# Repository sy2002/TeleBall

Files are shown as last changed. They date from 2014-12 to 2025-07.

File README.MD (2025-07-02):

TeleBall - Retro Handheld Game Console
======================================

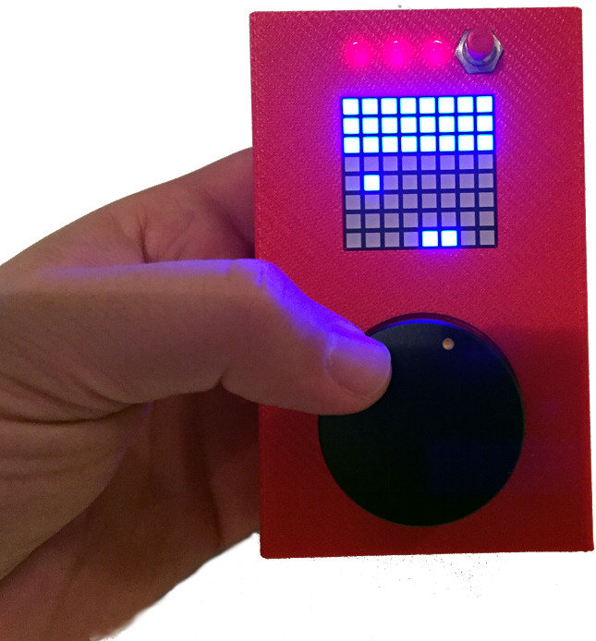
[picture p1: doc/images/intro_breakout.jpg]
DeviceInHand


What is TeleBall?
-----------------

TeleBall is a handheld game console. You cannot buy it. You need to build it
by yourself. It lets you play **BreakOut** in single-player mode using one
device and **Tennis for Two** in multi-player mode using two devices 
communicating via radio.

TeleBall is pretty retro and very minimalistic: It features an
8x8 pixel LED matrix display, a paddle as game controller and one button.
Therefore, the range of possible games is limited but you will be surprised
how much fun and even zenlike meditation this kind of gameplay can bring you,
particularly when you play Tennis for Two with a friend.

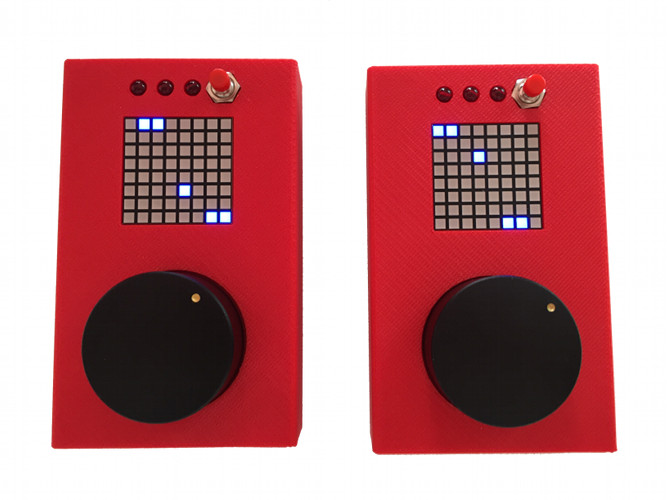
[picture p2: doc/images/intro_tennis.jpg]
TennisOnTwoDevices


About this GIT Repository
-------------------------

This repository contains everything you need to build your own TeleBall
device:

* CAD .stl and .cmb.gz data for your 3D printer or for any online 3D print
  shop to 3D print the TeleBall case

* Eagle PCB layout for any online PCB manufacturer to make the TeleBall PCB

* Part lists and hints how to build the hardware

* Arduino source code to flash the firmware

TeleBall is made using the
[Arduino Nano platform](https://store.arduino.cc/arduino-nano) on a
custom PCB.

Browse TeleBall's [project page](http://sy2002.github.io/TeleBall)
for a much better documentation, including a how-to play and
how-to build guide and a bill of materials (BOM). The project page
is also available offline using `index.html` in the root folder of
this repository.

### Folder Structure

    cad:    CAD data for 3D printing the TeleBall case
            Use ".stl" to modify the design or to create a custom output file.
            Most online 3D print shops can use the ".cmb.gz" for production.
            Made with FreeCad: https://FreeCAD.Org

    doc:    HTML documentation; use `index.html` in root folder to browse

    eagle:  Electronic schematic diagram including PCB layout.
            The libraries.zip files are only needed, if you want to modify
            anything; otherwise you can just send the ".brd" file to any
            online PCB manufacturing company to receive a TeleBall PCB.
            Made with the freeware version of Eagle: http://www.cadsoftusa.com

    src:    Arduino source code aka Sketch in the subfolder "TeleBall".
            Compile and upload it to your device using Arduino's IDE. You need
            to install the libraries from libraries.zip first, before being
            able to compile. The "archive" folder contains historic versions.
            Made with Arduino: http://arduino.cc/de/Main/Software

The Makers
----------

TeleBall is brought to you by

* [sy2002](http://www.sy2002.de): idea, code and original circurit design
* doubleflash: additional circurit design and board layout
* lamags: body housing/case

TeleBall was designed, built and released as an Open Source / Open Hardware
project during August 2014 and January 2015.

TeleBall is a project of 
[MEGA - Museum of Electronic Games & Art](http://www.m-e-g-a.org/diy-teleball/).

We are looking forward to hearing from you. Email to sy2002 at teleball.org

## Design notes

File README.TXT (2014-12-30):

==============================================================================

    T E L E B A L L 

    Retro style Arduino based BreakOut & Tennis game
    made in August .. December 2014
    
    * idea, code and original circurit design by sy2002
    * additional circurit design and board layout by doubleflash
    * body housing/case by Miro
    
    License: You are free to share and adapt for any purpose,
    even commercially as long as you attribute to
    sy2002, doubleflash and Miro and link to http://www.sy2002.de
    
    http://creativecommons.org/licenses/by/4.0/    

==============================================================================

* TeleBall is fun to play! It offers two play modes: A 3-level BreakOut clone
  as a single player game and a two player Tennis game using radio to connect
  two TeleBall devices. It is delighting to see, how much fun playing on a
  8x8 dot matrix display using a poti-controller can be.

* TeleBall is made using the Arduino Nano platform on a custom PCB.

* Open index.html with a browser to get a much better project documentation,
  how-to play and how-to build guide and a bill of materials (BOM).

* Folder structure:

    cad:    CAD data for 3D printing the TeleBall case
            Use ".stl" to modify the design or to create a custom output file.
            Most online 3D print shops can use the ".cmb.gz" for production.
            Made with FreeCad: http://www.freecadweb.org

    doc:    HTML documentation; use "index.html" in root folder to browse

    eagle:  Electronic schematic diagram including PCB layout.
            The libraries.zip files are only needed, if you want to modify
            anything; otherwise you can just send the ".brd" file to any
            online PCB manufacturing company to receive a TeleBall PCB.
            Made with the freeware version of Eagle: http://www.cadsoftusa.com

    src:    Arduino source code aka Sketch in the subfolder "TeleBall".
            Compile and upload it to your device using Arduino's IDE. You need
            to install the libraries from libraries.zip first, before being
            able to compile. The "archive" folder contains historic versions.
            Made with Arduino: http://arduino.cc/de/Main/Software

Last modified by sy2002 on 29th of December 2014

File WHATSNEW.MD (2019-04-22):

TeleBall - Version 1.4 - 04/22/19
---------------------------------

Improved documentation and website: Updated outdated links and increased
the font size to fit better to 2019 website styles.

TeleBall - Version 1.3 - 06/03/16
---------------------------------

Improved documentation: Updated the Bill of Material (BOM) in the
"Electronics" section (some links and some part numbers where outdated).

From a technical perspective, Version 1.3 is identical to Version 1.2.

TeleBall - Version 1.2 - 01/01/15
---------------------------------

* Change: The brightness adjustment has been moved to the advanced
  configuration mode, as usage tests showed that it is far less often used
  than the speed adjustment, and therefore it started to annoy soon.

* Change: Advanced menu: If you set the leftmost paddle position identically
  to the rightmost paddle position, then no paddle change is assumed. The
  idea is to be able to skip quickly through this menu setting without the
  necessity to set the paddle position each time.

* Change: The minimum speed is now faster (500ms instead of 600ms delay per
  pixel) and the maximum speed is now also faster (50ms instead of 75ms).

* Bugfix: The "X" in the EEPROM menu was not always accessible.

* Bugfix: You were not able to catch a ball that was already one line above
  the paddle and THEN you moved the paddle below it - even if you were fast
  enough that you should have catched this ball. 

* Bugfix: With a speedy paddle movement you could influence the ball even if
  the ball was far away from the paddle.

* Bugfix: Sometimes when adjusting the speed and the controller wheel was at
  the very left position, you saw no pixels illuminated while exactly one
  should have.

* Bugfix: The EEPROM fingerprint was not written on new devices, which means
  that new devices did not remember any settings, i.e. the EEPROM feature was
  broken there.

* Bugfix: The advanced menu already opened after a ~1sec button press instead
  after a ~4sec button press.

* Bugfix: Tennis: The pairing of two devices did not work, when one was in the
  won or lost state of BreakOut, while the other one was powered on. There
  were also some other states that prevented pairing, so this should be rock
  solid now.

* Bugfix: Tennis: When one of the players suddenly switched off his device or
  walked out of the radio range (or similar events), then the other device was
  left in an undefined state. Now it goes back to BreakOut.

* Bugfix: Tennis: Sometimes the won or lost smiley stayed visible, on the
  slave's screen when the master device was resetting the match.

* Bugfix: Tennis: If the game speed was set on the slave device, then when
  leaving the configuration menu, there was no short game pause and the ball's
  position and direction was random, which sometimes lead to weird results
  like left/right bouncing balls.

* Bugfix: Tennis: If during pairing a player pressed the button while waiting
  for the other player to join, the device went into an undefined state.

* Bugfix: Tennis: If during pairing a player pressed the button immediatelly,
  i.e. if he did not wait for the initial "?" to disappear, unwanted effects
  could occur.

* Bugfix: Tennis: When the slave device was the last to acknowledge to play
  tennis, then there was no delay, before the game started.

* Bugfix: Tennis: When the configuration menu was entered while the ball was
  still in pause mode (e.g. directly after a lost ball), then when leaving
  the configuration menu lead to a freezing ball, i.e. it did not start moving
  again at all; you needed to reset the match.

* Optimization: Saved SRAM by moving constant lookup-tables to PROGMEM.

TeleBall - Version 1.1 - 12/24/14

* Bugfix: BreakOut: When solving the game, i.e. when the third level is
  successfully mastered, the applause sound is played and the smiley face
  is shown.

* EEPROM: The device is now able to permanently store user preferences. For
  doing so, enter the advanced config menu by pressing the button 4 seconds
  while being in the standard menu. After configuring the paddle, you can now
  choose "square" for saving your preferences or "X" to revert back to the
  factory default values.

TeleBall - Version 1.0 - 12/21/14

* First release on final TeleBall hardware

TeleBall - Version 0.1 - 8/3/14

* The very first version of TeleBall was developed on the Arduino experimentor
  platform DuinoKit: http://duinokit.com/ShowAndTell/viewtopic.php?f=4&t=14

Last modified by sy2002 on 3rd of January 2015

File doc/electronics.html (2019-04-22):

# TeleBall

Build your own Arduino retro handheld game console

- Home
- Play
- Case
- Electronics
- Software
- Download ZIP (https://github.com/sy2002/TeleBall/zipball/master)
- Download TAR (https://github.com/sy2002/TeleBall/tarball/master)
- View On GitHub (https://github.com/sy2002/TeleBall)

This project is maintained by sy2002 (http://www.sy2002.de)

# TeleBall Electronics

## Schematics

Schematics Overview

- BAT+ / BAT-: Battery+ and Battery- aka GND, directly wired via battery clips
- +UB: 6 V battery power (coming from BAT+) but after the on/off switch
- +3V3: 3.3 V regulated by IC2 VREG3, needed by the radio SV1
- MODUL1 ARDUINO: Microcontroller - see details below
- KWM-R30881CBB: 8x8 LED Display - see details below
- IC1 MAX7221CNG: LED Display Driver - see details below
- SV1: nRF24L01+ Radio - see details below
- IC2 VREG3: Voltage Regulator - see details below
- SCHALTER: TeleBall power switch / on/off switch
- LED1, LED2, LED3: ball / score indicator LEDs
- BUTTON+ / BUTTON-: Reverse logic button +/-, i.e. not pressed = current flowing
- LS+ / LS-: Speaker +/-
- POTI+, POTI-, POTI_S: 10kΩ potentiometer’s +, - and signal line
- C2: 10 µF current buffer (capacitor) for MAX7221
- C1, C3, C4: 100 nF anti-oscillation capacitors
- R2: 24.9 kΩ voltage and current selector resistor for MAX7221
- R5, R6, R7: 8.2 kΩ series resistor for LEDs
- MOSI, MISO, SCK, IRQ, CSN, CE: Wiring that connects the Arduino with the Radio
- DATAIN, CLOCK, LOAD: Wiring that connects the Arduino with the LED Display Driver
- DIGx (x = 0 .. 7), SEGy (y = A .. G, DP): Wiring that connects the LED Display Driver with the 8x8 LED Display.

Download TeleBall’s detailed Schematics PDF. The subfolder eagle of your TeleBall package contains all schematics including the PCB design. We used the Freeware version of the specialized CAD software Eagle (https://www.autodesk.com/products/eagle/free-download) to create the schematics and the board layout (PCB design).

### The Circuit Explained

The following parts are the main parts of the circuit:

- Microcontroller: 5V version of Arduino Nano 3.0 or compatible device (Data Sheet (https://store.arduino.cc/arduino-nano))
- 8x8 LED Display: KWM-R30881CBB aka AdaFruit 1817 (Data Sheet (http://www.adafruit.com/datasheets/1047datasheet.pdf))
- LED Display Driver: MAX7221 (Data Sheet (http://datasheets.maximintegrated.com/en/ds/MAX7219-MAX7221.pdf))
- Radio: nRF24L01+ on an Arduino friendly breakout board (Data Sheet (http://www.nordicsemi.com/eng/content/download/2726/34069/file/nRF24L01P_Product_Specification_1_0.pdf))
- Voltage Regulator: Rohm BD33KA5FP-E2 (Data Sheet (http://rohmfs.rohm.com/en/products/databook/datasheet/ic/power/linear_regulator/bdxxka5-e.pdf))

Some basics about how these main parts work together:

- The Arduino is the heart of TeleBall. Using its Harvard architecture, we are able to store the program code itself on (32kB Flash) as well as configuration data (1kB EEPROM). Additionally, it features SRAM (2kB). The built-in USB port in conjunction with Arduino’s bootloader allows us to update TeleBall’s firmware easily. The Arduino has a built-in current regulation, so we can directly connect it to UB+.
- As each pin of the Arduino is able to supply 40mA, the Arduino can directly drive the three status LEDs and the speaker. Pin D9 is a PWM (Pulse-width modulation) capable pin; this is important to generate tones via software.
- The 8x8 LED matrix has 64 LEDs but only 16 pins. That means, that you need to scan through the matrix (either line by line or column by column) very quickly to control it pixelwise. The MAX7221 is doing this automatically, so the Arduino just needs to transmit the desired pattern. This is done using the digital output pins D2, D3 and D4, that communicate via the SPI protocol with the MAX7221 display driver.
- The Led Matrix Driver MAX7221 is not only controlling the 8x8 LED matrix but also driving it by supplying voltage and current for the actual operation of the LEDs. The MAX7221 allows up to 6V voltage at its VCC pin. We are therefore directly connecting it to the battery current UB+, which is initially - as long as the batteries are new/full - indeed 6V but dropping during the lifetime of the batteries.
- The wiring of the MAX7221 to the 8x8 LED matrix might look a bit weird: This is mainly because of the inner workings of the LED matrix, that is internally not wired linearly. For example, as described in the Data Sheet (http://www.adafruit.com/datasheets/1047datasheet.pdf), LED row #1 is mapped to pin #9 and LED column #2 to pin #3. The MAX7221 is supplying current at SEG DP, SEG A .. SEG G and sinking current from the display’s common cathode at DIG 0 .. DIG 7.
- The radio is able to cope with 5V control lines, i.e. Arduino’s digital outputs MOSI, MISO, SCK, IRQ, CSN, CE but it cannot be driven by 5V. This is why we use the Rohm voltage regulator that converts the up to 6V UB+ to a stable 3.3V. The names of the signal lines MOSI/MISO/etc. might be misleading a bit: The whole radio SPI control is done in software, we are not using any hardware SPI features and therefore we could have wired the radio differently, when it comes to digital ports at the Arduino.
- We used high intensity LEDs, this is why the series resistors R5, R6, R7 are having such high Ohm values. If you plan to use normal / weaker LEDs, then you could use 1kΩ resistors instead.
- The software activates the internal pull-up resistor of the digital input D8 and uses an inverse logic. Therefore it expects a button that also uses reverse / inverse logic, i.e. no current when pressed and current when not pressed.
- TeleBall’s main game control, the “paddle” or “knob”, is implemented using a 10kΩ potentiometer that connects with the Arduino’s 10bit-A/D analog input A7. (Note, that TeleBall’s firmware configures the other Ax analog pins, particularly A0, A1 and A2 as digital outputs.)

## Important Files

All files related to TeleBall’s electronics are Eagle (https://www.autodesk.com/products/eagle/free-download) files, so you find them in the eagle folder.

BreakOut-8x8-rev2.sch      Eagle schematics file. The above-mentioned
                           schematics are contained here.
BreakOut-8x8-rev2.brd      Eagle PCB layout file. The below-mentioned
                           board layouts are contained here.
libraries.zip              As the .sch and .brd files are self-contained,
                           you only need the Eagle libraries from the ZIP,
                           if you want to dig deeper, e.g. modify details
                           of parts.

## Custom Printed Circuit Board (PCB)

To get a custom PCB you just need to send the file BreakOut-8x8-rev2.brd from the eagle folder of the TeleBall package to the online PCB manufacturer of your choice. The .brd file contains the multiple layers of which your PCB is consisting of:



And this is how the result, i.e. the custom manufactured PCB should basically look like:



The left side shows the top side of the PCB, the gap at the top right is for the red button, the so called Universal Button (reset, configuration, confirmation, etc). Download the high-resolution version of the PCB Photo.

## Assembly Diagram

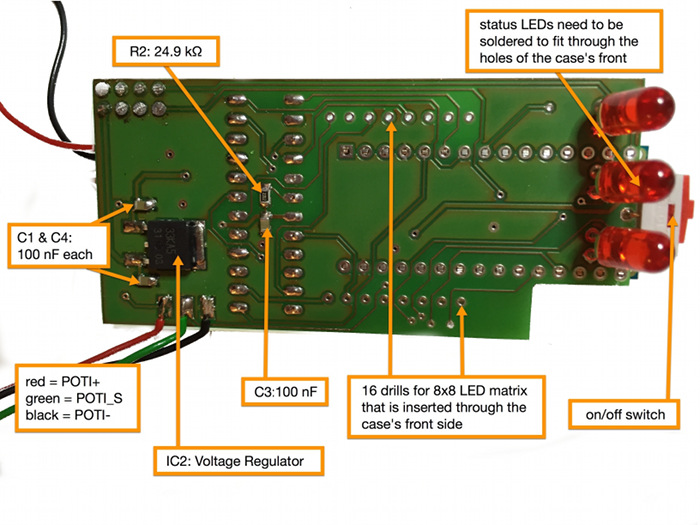
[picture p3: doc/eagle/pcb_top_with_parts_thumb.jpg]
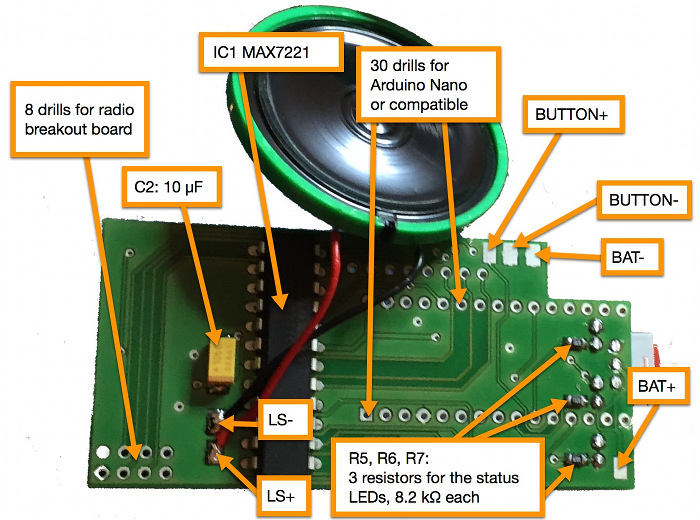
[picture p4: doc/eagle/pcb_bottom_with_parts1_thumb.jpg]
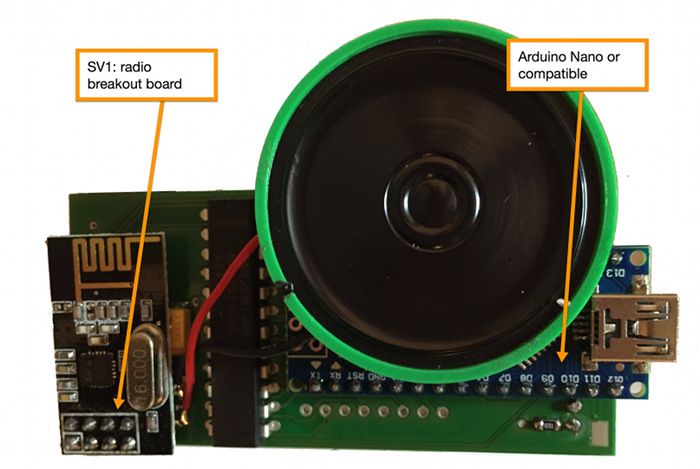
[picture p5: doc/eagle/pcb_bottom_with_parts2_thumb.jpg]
  

Download high-resolution versions of the assembly diagrams: Top Layer Photo and Bottom Layer Photo

### Some Hints for Assembling and Soldering TeleBall

- You might want to print out the above-mentioned high-resolution versions of the graphical assembly diagrams. Additionally, the high-resolution PDFs of the board schematics might be useful, too: Top Layer Schematics and Bottom Layer Schematics
- How to solder the SMD parts (like the capacitors Cx or the resistors Rx): Tin-coat one pad; while the tin-solder is still liquid, use a pair of tweezers to place the SMD part; as the tin-solder cools down, the SMD part starts to sit firm; now heat the second pad and let the tin-solder flow below the SMD part; let it cool down again; done.
- Solder all SMD parts (top and bottom side of the PCB) first, including the voltage regulator (IC2 VREG3). Then go on with MAX7221 (IC1). Then do the on/off switch (SCHALTER) and after that the LEDs and the cables for the speaker (LS+ and LS-) as well as the cables for the potentiometer. Only then, solder the Arduino (MODUL1 ARDUINO) and the radio breakout board (SV1). The reason for this suggested soldering order is, that some of the larger parts like the Arduino and the radio breakout board are hiding some of the smaller parts and some of the cables.
- You need to cut the legs of the ICs after you soldered them. Cut the Arduino Nano “head” pins before soldering it (they would interfere with the speaker if not cut).
- Before you marry the PCB and the case as described in the next bullet point, be sure that you added the battery clips before (see next section).
- The 8x8 LED matrix is the last part of TeleBall that you solder: Insert it through the case’s front side (there are dedicated holes for that) while holding the PCB against the inside of the case. While doing so, you are basically filtering in the 8x8 LED matrix through the case as well as through the PCB and therefore, this action “glues” both elements together.
- Be mindful about the length of the cables. We advise to use red cables for +, black cables for - and other colors for signal cables. Additionally, we recommend to strip the insulaton at the cable ends and to tin-coat them.

### Battery Clips

The case as well as the lid feature special places where the battery clips / battery springs need to be added. As shown in the image below, there are two kinds of battery clips: Flat clips and clips with springs. We bought just one variant - with springs - and created the other kind by cutting off the spring.There is a different treatment of the battery clips in the case versus the battery clips in the lid:

- Case: If you look at the back side of the case with the open facing side down and the side which will hold the on/off switch and the USB port facing up, then after inserting the battery clips on the top/right and top/left side, you should solder a red wire at the right clip. After the marriage of the PCB and the case, you would solder the red wire to the BAT+ pad on the PCB. Furtheron you should solder a black wire at the left clip and later, after the marriage, solder it to the BAT- pad. The top right clip is without a spring and the top left clip is with a spring.
- Lid: As shown in the image below, insert two battery clips into the lid and connect both with a wire. Be mindful not to have two springs at the same side, i.e. if you followed the above-mentioned instructions about the springs, then you should place the clip with a spring in the lid just as shown in the image below.



## Bill of Materials

Image | ID | Description | Where to get it
Case | Case | TeleBall Case and Lid | 3D print it (or have it 3D printed) as described in Case
PCB | PCB | Custom printed circuit board | Have it manufactured as described in this chapter.
MODUL1 ARDUINO | MODUL1 ARDUINO | Arduino Nano or compatible device | Original Arduino Device (https://store.arduino.cc/arduino-nano) or search for “arduino 3.0 nano 5v” on eBay to find compatible devices / clones
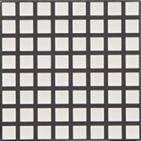
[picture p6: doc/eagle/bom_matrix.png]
KWM- R30881CBB
 | KWM- R30881CBB | The Adafruit KWM-R30881CBB is a 30x30mm blue 8x8 LED matrix display featuring row cathodes. | Visit the Adafruit store and find part #1817 (http://www.adafruit.com/products/1817). Seems to be Adafruit exclusive, as we did not yet find alternative vendors for this device, yet.
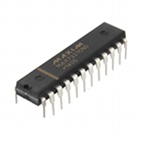
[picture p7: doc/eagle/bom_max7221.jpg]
IC1
 | IC1 | The MAX7221CNG+ is the display driver of the TeleBall. | Standard / Farnell 2516083
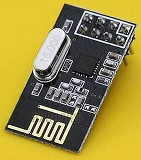
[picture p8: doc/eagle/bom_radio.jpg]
SV1
 | SV1 | NRF24L01+ 2.4GHz Antenna Wireless Transceiver Module for Arduino on a breakout board | There are plenty of vendors on ebay selling this. Search for NRF24L01+ Arduino.
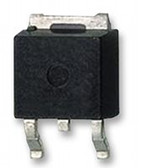
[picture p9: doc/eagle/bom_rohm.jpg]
IC2 VREG3
 | IC2 VREG3 | Rohm voltage regulator part number BD33KA5FP-E2. | Standard / Farnell 2342845
SCHALTER | SCHALTER | EAO 09.10201.02 switch with pins bent at right-angles | Standard / Farnell 1608081
LED1, LED2, LED3 | LED1, LED2, LED3 | MULTICOMP 5mm Round LED Lamp, 20 mA. You need 3 of them per TeleBall. | Standard / Farnell 2112111
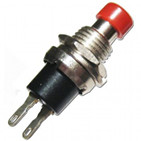
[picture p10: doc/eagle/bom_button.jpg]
BUTTON
 | BUTTON | Focan Electronic (http://focan.en.alibaba.com/) PBS-10C-2 reverse-logic button. If you need to find an alternative, use the datasheet (http://www.pollin.de/shop/downloads/D420320D.PDF) to get the exact specs. | Not that easy to find. Try Amazon, eBay, Alibaba; googling PBS-10C might also help. There might be similar buttons available, if you search for “pbs push button”. IMPORTANT: The PBS-10C-2 is a reverse-logic button, that closes the circuit when not being pressed and opens it when being pressed. If you use another button type, you might need to adjust this line of code (https://github.com/sy2002/TeleBall/blob/master/src/TeleBall/TeleBall.ino#L1128).
LS | LS | Thin Speaker, 39.6mm diameter, 4.5mm height, 8 Ω impedance, 0.25 W | Sparkfun part COM-10722 (https://www.sparkfun.com/products/10722) or Adafruit part #1891 (http://www.adafruit.com/products/1891)
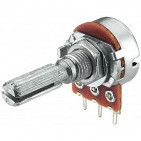
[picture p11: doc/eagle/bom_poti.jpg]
POTI
 | POTI | Monacor VRB-141M10 10 kΩ linear mono potentiometer, 6mm shaft diameter, 25mm shaft length + 9,5mm body. If you need to find an alternative, use the datasheet (http://www.monacor.co.uk/categories/potentiometers/vnr/012620/) to get the exact specs. | Monacor UK shop article VRB-141M10 (http://www.monacor.co.uk/categories/potentiometers/vnr/012620/), click on “Find Your Retailer” on the right sidebar. Alternately google for “Monacor VRB-141M10 10k linear mono potentiometer”.
C2 | C2 | 10 µF Tantal SMD capacitor 805 package | Standard / Farnell 197270
C1, C3, C4 | C1, C3, C4 | 100 nF SMD capacitor 805 package. You need 3 of them per TeleBall. | Standard / Farnell 644160
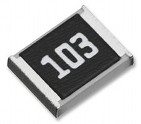
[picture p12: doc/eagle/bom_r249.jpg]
R2
 | R2 | 24.9 kΩ SMD resistor 805 package | Standard / Farnell 2057643
R5, R6, R7 | R5, R6, R7 | 8.2 kΩ SMD resistor 805 package. You need 3 of them per TeleBall. | Standard / Farnell 1887306
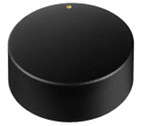
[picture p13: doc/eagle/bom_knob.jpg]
Knob
 | Knob | Black aluminum rotary knob, 40mm diameter for 6mm shaft | Not easy to find. Try eBay’s Audio Knobs Section (http://www.ebay.com/bhp/audio-knobs) or google for Black aluminum rotary knob, 40mm diameter for 6mm shaft, sometimes vendors call it a “Volume Control Potentiometer Knob”.’
Battery Clip | Battery Clip | KEYSTONE BK5201 Battery Clip, 11.2x12.0 mm, 0.8 mm height of the foot, 10.5mm height including spring. You need 4 of them per TeleBall. Get the specs here (http://www.luedeke-elektronic.de/images/product_images/popup_images/4836_1.jpg) if you need to find an alternative. | Not easy to find. Amazon or eBay sometimes have it. Google for KEYSTONE BK5201 or KEYSTONE BK5201 Battery Holder or similar combinations.

Some hints about “Where to get it”:

- As the world of electronics is very fast paced, it might be that some of the sources mentioned here will not be active any more when you visit this page. Please inform us via email: sy2002 at teleball.org, if you discover that.
- The term “Standard / Farnell: " means: This is a pretty standard part; you should get it "everywhere", i.e. enter the part name in google. Additionally we supply a Farnell part in this cases. Farnell is a very international distributor so it is very likely, that it is available in your country, too. Head to www.farnell.com and copy/paste the into Farnell's search bar.
- You can also use www.findchips.com to find vendors for the parts.
- In general: If you cannot find a certain part at all, it might make sense to search for a similar alternative from another vendor. The drawback in this case might be, that the case might need some small adjustments.

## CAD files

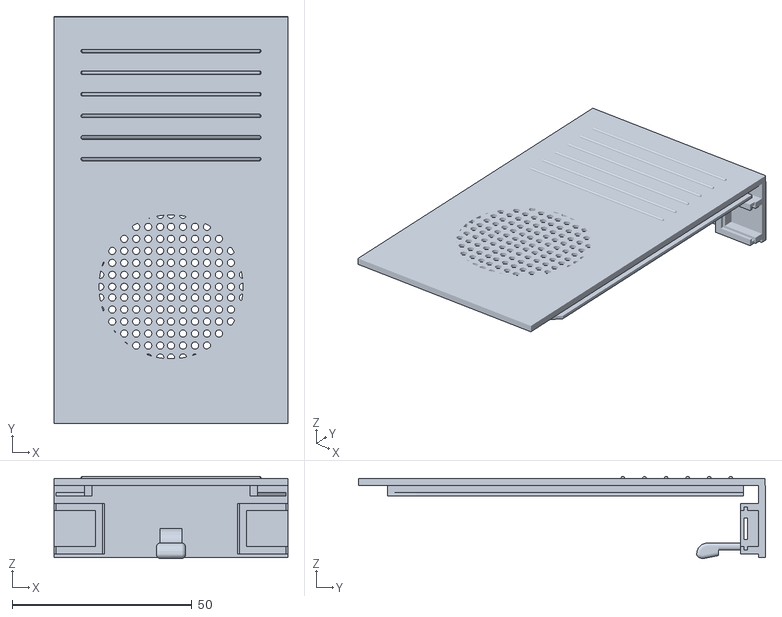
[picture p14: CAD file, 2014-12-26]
cad/case_lid_v2.stl
65.0 x 113.1 x 22.8

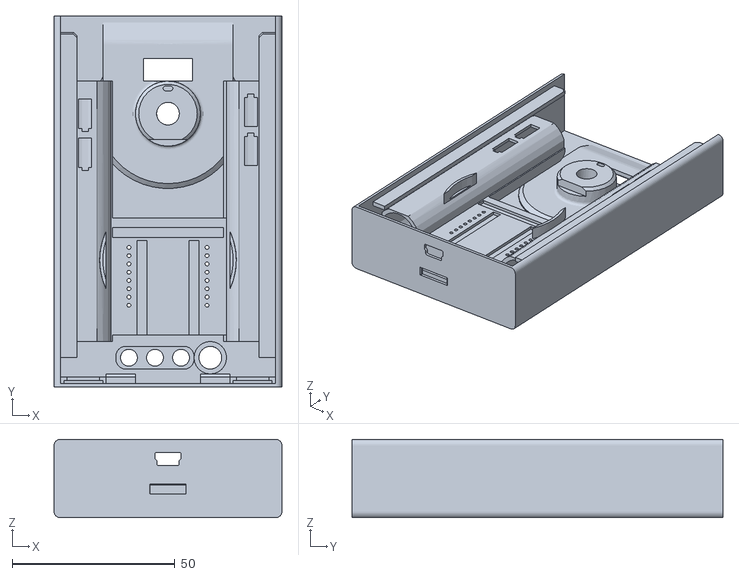
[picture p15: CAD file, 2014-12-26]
cad/case_body_v2.stl
70.0 x 114.0 x 24.0

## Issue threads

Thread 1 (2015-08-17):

Having Trouble with the Source code

davisaces, 2015-08-17:
Hello, My name is Christopher Davis and I am a Bachelors student using your teleball project for my capstone.  I have came across some issues with the source code. We have included the #include<LedControl.h>, #include<nRF24L01.h>, and the #include<RF24.h> from the websites given in the code. When we try to compile the code we get an error "Ledcontrol.h:30:error:'byte'does not name a type.  Can you please contact me and let me know what I'm doing wrong? Thank you very much

Christopher J. Davis

sy2002, 2015-08-18:
Hi Christopher,
if the "LED control" library and the "NRF24L01+ radio driver class" are installed correctly, then there should be no need to change anything in the code, it should just compile.

So my first idea would be, that you might not have installed them correctly. Please have a look at this tutorial video I made a while ago, that explains, how to install them:

https://www.youtube.com/watch?v=OP6eKLpfZnA

(Attention: The project shown in the tutorial video is a predecessor to TeleBall, so the code is not compatible as it is another project. But it shows the basic principle of how to install the libraries correctly, so that TeleBall's code can make use of it.)

A second idea might be, that in the meantime, i.e. since I wrote TeleBall and today, the libraries might have become incompatible, e.g. because they changed their APIs or so. In that case: Instead of downloading the newest version of the libraries from the web locations mentioned in the code, please use the versions that I supplied together with the TeleBall release bundle on GitHub:

https://github.com/sy2002/TeleBall/archive/V1.2.zip

If you unzip it, you'll find a folder named "src" and there is another ZIP called "libraries.zip". These are the original library version that I used to build TeleBall. You might want to install them as shown in the video above - instead of using the most recent versions from the web.

Best regards
  sy2002

davisaces, 2015-08-19:
Sy2002,
Thak you! We put the original libraries as u suggested. You are the man.

God bless
Chris
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

sy2002, 2015-08-20:
Hi Chris,
great to hear that this solved your problem! :-)
I am curious: Are you guys building the whole TeleBall device, including 3D printing, custom PCB, etc.?
Best regards
sy2002

davisaces, 2015-08-21:
No sir.  It was rather pricey so we decided to put it on the bread board.
We couldn't find a 3d printing company around to do so in the matter of
time we had and the custom PCB boards cost too much. I wish we could have
done it, but with the time and and budget, it wasn't feasable.

Thanks again,
Chris

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

Closed 2015-08-20.

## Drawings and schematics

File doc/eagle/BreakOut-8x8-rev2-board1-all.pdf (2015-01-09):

2 | 1 | 3
LED1 | LED2 | LED3

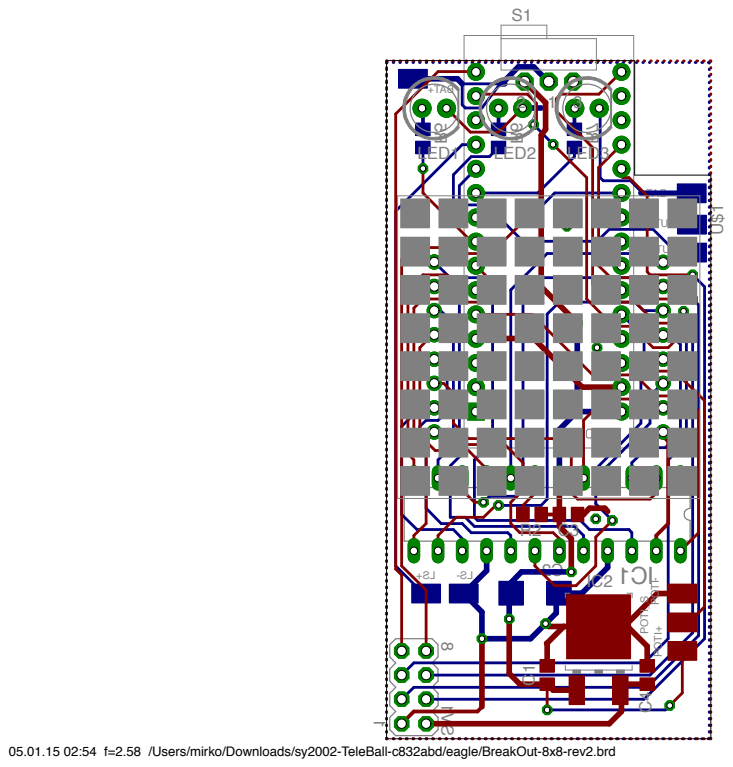
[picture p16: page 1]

05.01.15 02:54 f=2.58 /Users/mirko/Downloads/sy2002-TeleBall-c832abd/eagle/BreakOut-8x8-rev2.brd

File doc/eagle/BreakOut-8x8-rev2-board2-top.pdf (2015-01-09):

LED1 | LED2 | LED3

S1

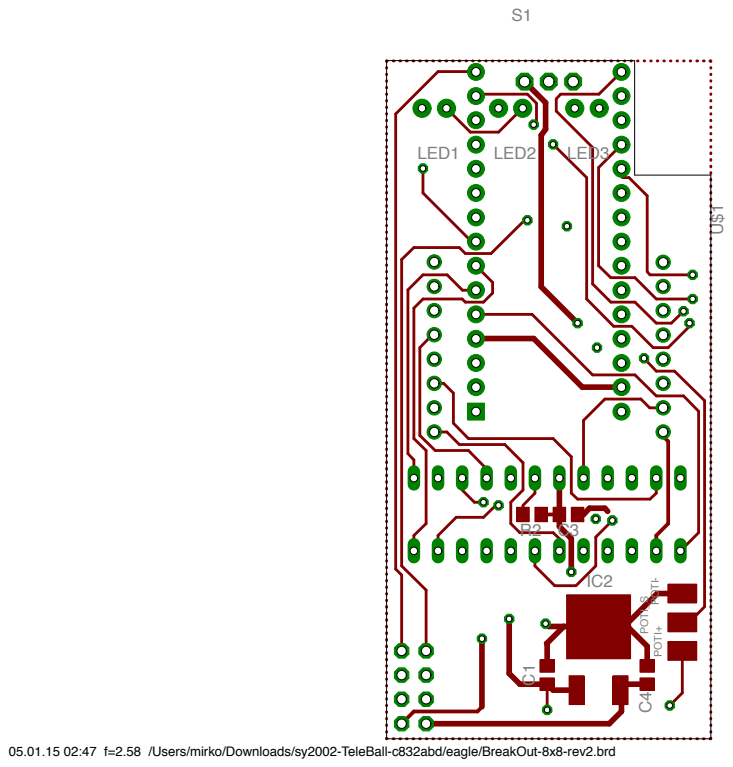
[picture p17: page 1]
POTI_S; POTI+ POTI-

05.01.15 02:47 f=2.58 /Users/mirko/Downloads/sy2002-TeleBall-c832abd/eagle/BreakOut-8x8-rev2.brd

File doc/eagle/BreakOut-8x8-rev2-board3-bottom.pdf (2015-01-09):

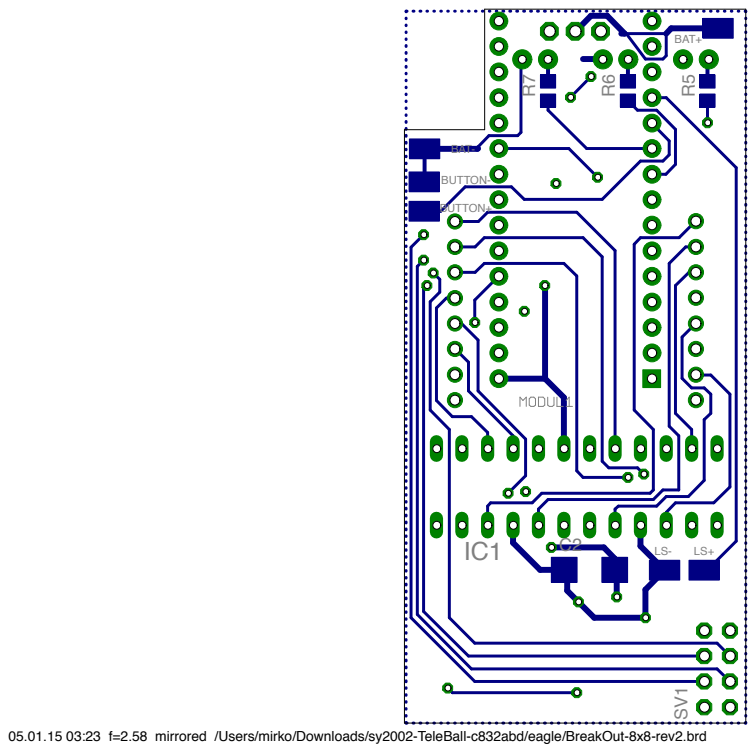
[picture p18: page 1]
BUTTON+; BUTTON-; BAT+; BAT-

05.01.15 03:23 f=2.58 mirrored /Users/mirko/Downloads/sy2002-TeleBall-c832abd/eagle/BreakOut-8x8-rev2.brd

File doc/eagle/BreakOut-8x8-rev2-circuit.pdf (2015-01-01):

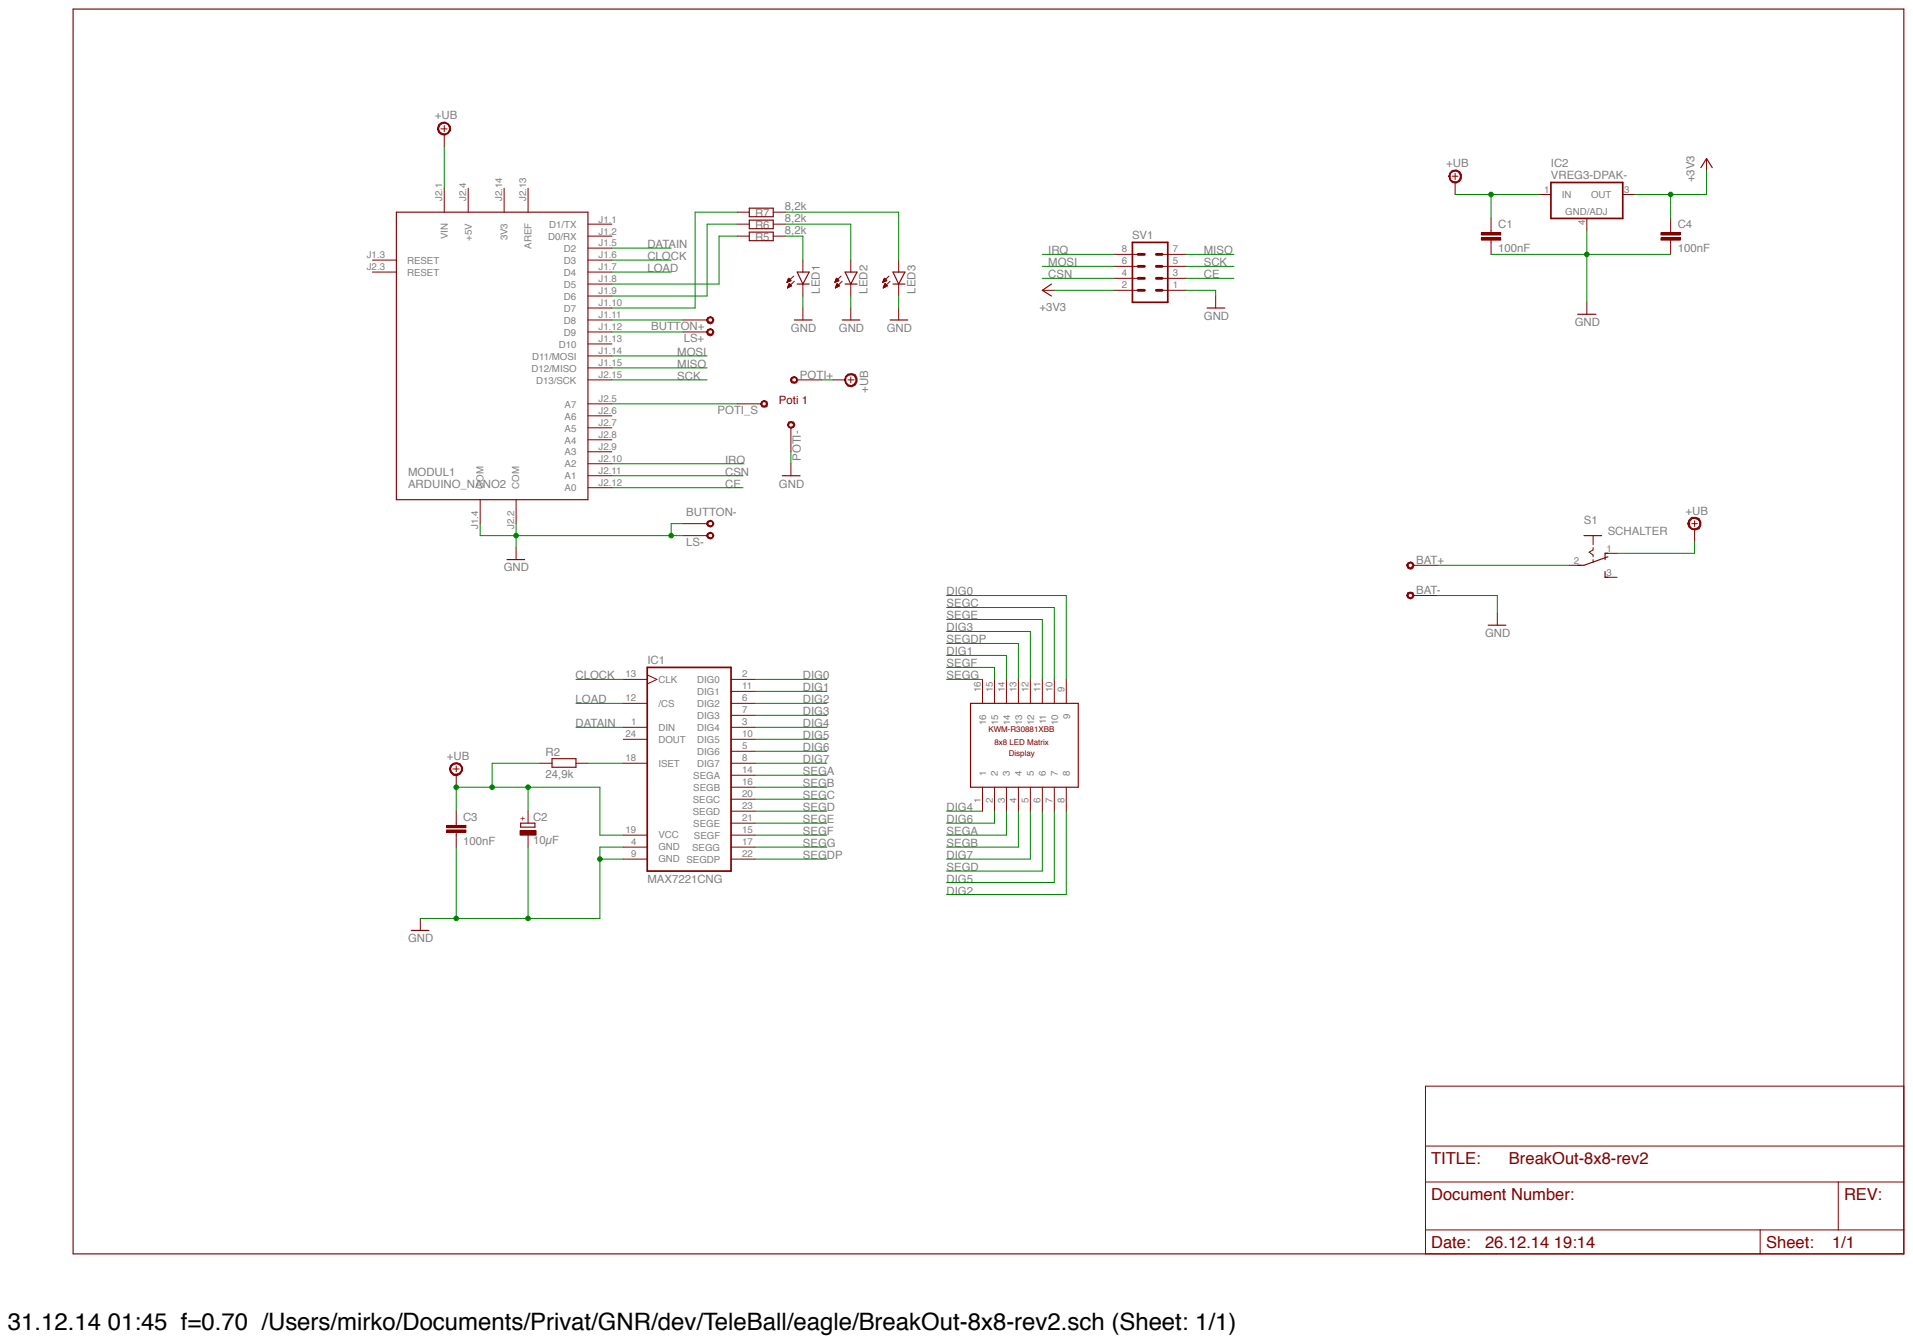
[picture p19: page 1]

Document Number: | REV:

Date: 26.12.14 19:14 | Sheet: 1/1

31.12.14 01:45 f=0.70 /Users/mirko/Documents/Privat/GNR/dev/TeleBall/eagle/BreakOut-8x8-rev2.sch (Sheet: 1/1)

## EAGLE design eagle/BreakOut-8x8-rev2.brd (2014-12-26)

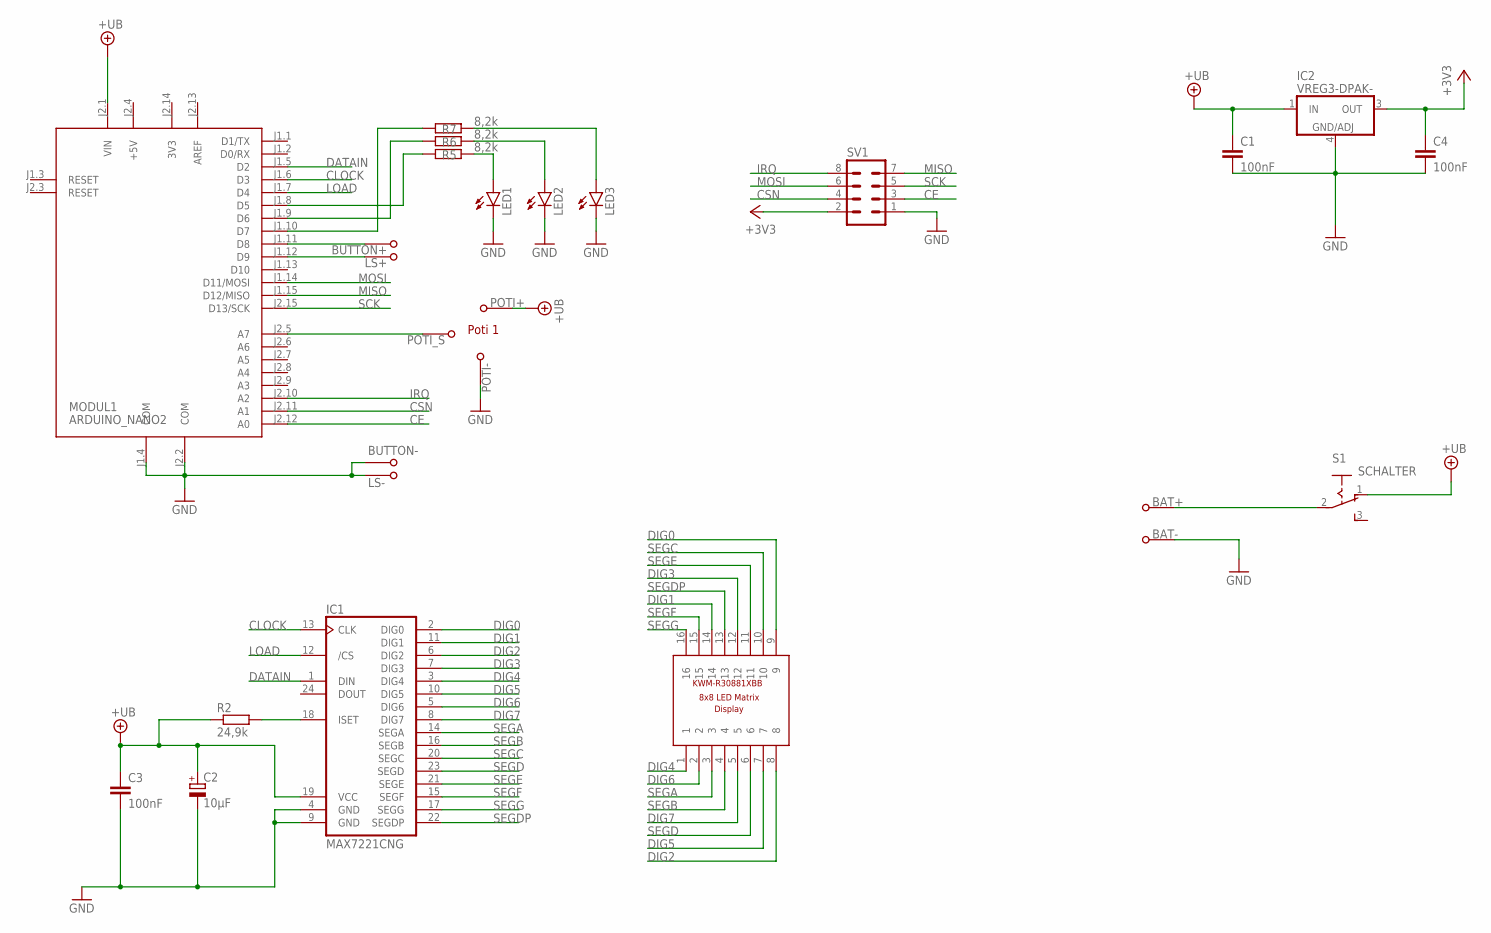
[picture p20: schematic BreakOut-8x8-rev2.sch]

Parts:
BAT+: PAD-NVSMD-2X3; PAD-SO-2X3
BAT-: PAD-NVSMD-2X3; PAD-SO-2X3
BUTTON+: PAD-NVSMD-2X3; PAD-SO-2X3
BUTTON-: PAD-NVSMD-2X3; PAD-SO-2X3
C1, C3, C4: 100nF; C0805
C2: 10µF; C/6032-28R
IC1: MAX7221CNG; DIL24-3
IC2: VREG3-DPAK-; DPAK
LED1, LED2, LED3: LED5MM
LS+: PAD-NVSMD-2X3; PAD-SO-2X3
LS-: PAD-NVSMD-2X3; PAD-SO-2X3
MODUL1: ARDUINO_NANO2
POTI+: PAD-NVSMD-2X3; PAD-SO-2X3
POTI-: PAD-NVSMD-2X3; PAD-SO-2X3
POTI_S: PAD-NVSMD-2X3; PAD-SO-2X3
R2: 24,9k; R0805
R5, R6, R7: 8,2k; R0805
S1: SCHALTER; 255SB
SV1: MA04-2
U$1: KWM-R30881XBB

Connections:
3V3: MODUL1.J2.14 (3V3)
+3V3: C4.1, IC2.3 (OUT), SV1.2
+5V: MODUL1.J2.4 (+5V)
+UB: C1.1, C2.+, C3.1, IC1.19 (VCC), IC2.1 (IN), MODUL1.J2.1 (VIN), POTI+.1, R2.1, S1.1
AREF: MODUL1.J2.13 (AREF)
BUTTON: MODUL1.J1.10 (D7), R7.1
CE: MODUL1.J2.12 (A0), SV1.3
CLOCK: IC1.13 (CLK), MODUL1.J1.6 (D3)
CSN: MODUL1.J2.11 (A1), SV1.4
DATAIN: IC1.1 (DIN), MODUL1.J1.5 (D2)
DIG0: IC1.2 (DIG0), U$1.9
DIG1: IC1.11 (DIG1), U$1.14
DIG2: IC1.6 (DIG2), U$1.8
DIG3: IC1.7 (DIG3), U$1.12
DIG4: IC1.3 (DIG4), U$1.1
DIG5: IC1.10 (DIG5), U$1.7
DIG6: IC1.5 (DIG6), U$1.2
DIG7: IC1.8 (DIG7), U$1.5
GND: BAT-.1, BUTTON-.1, C1.2, C2.-, C3.2, C4.2, IC1.4 (GND), IC1.9 (GND), IC2.4 (GND/ADJ), LED1.K (C), LED2.K (C), LED3.K (C), LS-.1, MODUL1.J1.4 (COM), MODUL1.J2.2 (COM), POTI-.1, SV1.1
IRQ: MODUL1.J2.10 (A2), SV1.8
LOAD: IC1.12 (/CS), MODUL1.J1.7 (D4)
MISO: MODUL1.J1.15 (D12/MISO), SV1.7
MOSI: MODUL1.J1.14 (D11/MOSI), SV1.6
unnamed: BUTTON+.1, MODUL1.J1.11 (D8)
unnamed: LED1.A, R5.2
unnamed: LED2.A, R6.2
unnamed: LED3.A, R7.2
unnamed: MODUL1.J2.5 (A7), POTI_S.1
unnamed: BAT+.1, S1.2
unnamed: LS+.1, MODUL1.J1.12 (D9)
unnamed: IC1.18 (ISET), R2.2
unnamed: MODUL1.J1.9 (D6), R6.1
unnamed: MODUL1.J1.8 (D5), R5.1
SCK: MODUL1.J2.15 (D13/SCK), SV1.5
SEGA: IC1.14 (SEGA), U$1.3
SEGB: IC1.16 (SEGB), U$1.4
SEGC: IC1.20 (SEGC), U$1.10
SEGD: IC1.23 (SEGD), U$1.6
SEGDP: IC1.22 (SEGDP), U$1.13
SEGE: IC1.21 (SEGE), U$1.11
SEGF: IC1.15 (SEGF), U$1.15
SEGG: IC1.17 (SEGG), U$1.16

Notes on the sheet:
Poti 1

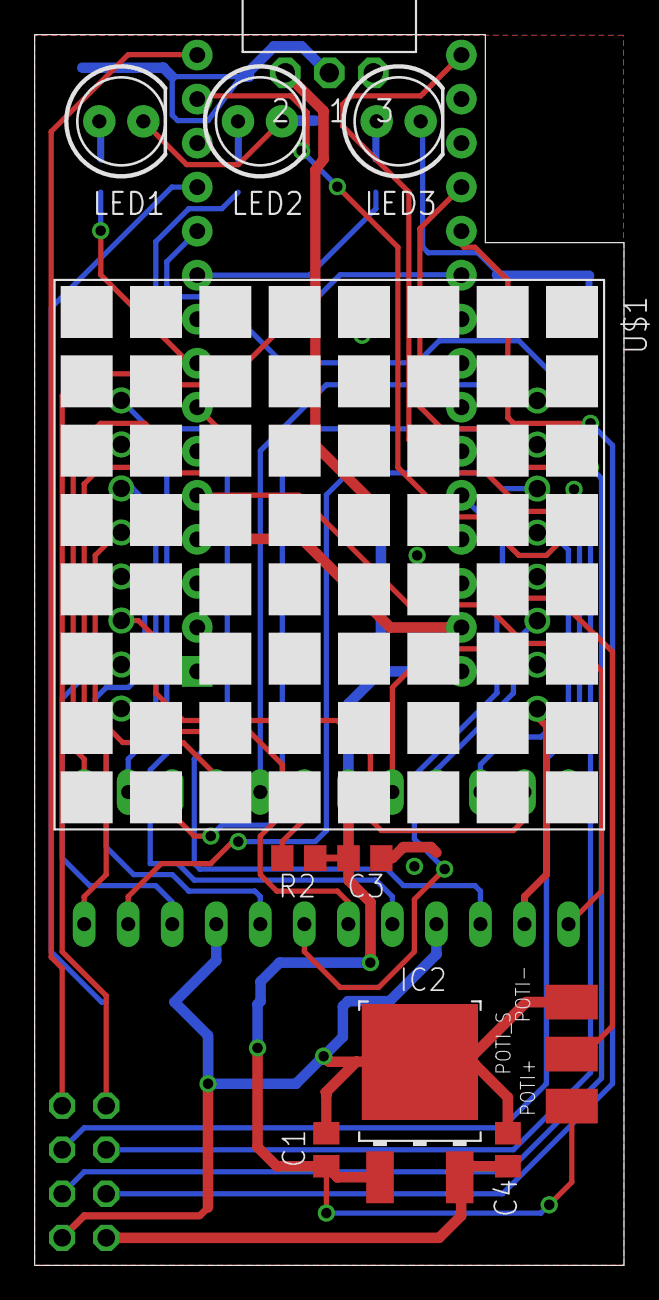
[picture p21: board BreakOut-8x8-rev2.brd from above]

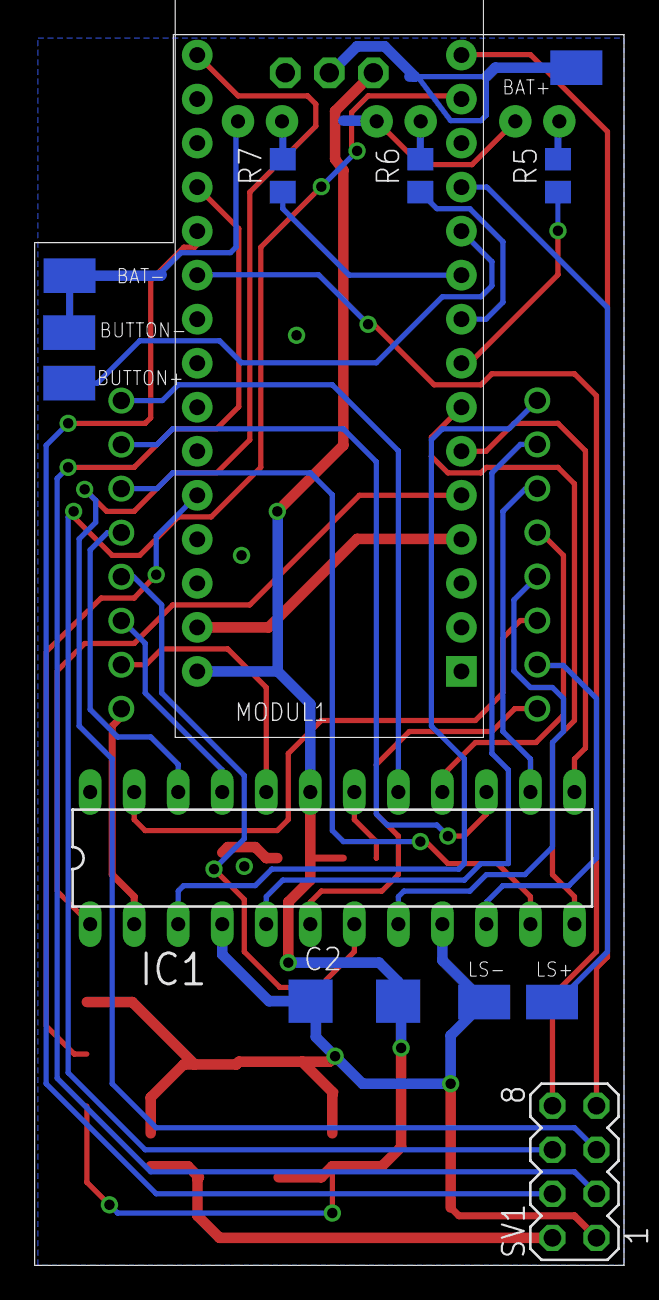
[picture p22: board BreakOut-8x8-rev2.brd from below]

Board: 2 copper layers, 34.0 x 71.0 mm, 26 parts (13 on the bottom side), 39 nets.

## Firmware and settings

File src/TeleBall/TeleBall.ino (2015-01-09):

/* ******************************************************************
    TeleBall
    
    Retro Style BreakOut and Tennis Game
    
    made in August 2014 .. January 2015
    
    * idea, code and original circurit design by sy2002
    * additional circurit design and board layout by doubleflash
    * body housing/case by lamags
    
    License: You are free to share and adapt for any purpose,
    even commercially as long as you attribute to sy2002 and
    link to http://www.sy2002.de
    
    http://creativecommons.org/licenses/by/4.0/    
   ****************************************************************** */

//#define DUINOKIT              //mirror x specifically for the DUINOKIT hardware
#define SHOW_MASTER_SLAVE     //show master/slave indicator in question mode
#define STAY_IN_TENNIS        //after tennis was entered once, stay in tennis mode

/* ******************************************
    Libraries
   ****************************************** */
      
//Arduino default EEPROM library for persistent storage
#include <EEPROM.h>

//Arduino default library for accessing the PROGMEM
#include <avr/pgmspace.h>
   
//MAX7221 LED control library
//information: http://playground.arduino.cc/Main/LedControl
//download:    https://github.com/wayoda/LedControl
#include <LedControl.h>

//NRF24L01+ radio driver class
//information & dl: http://tmrh20.github.io/RF24/
#include <SPI.h>
#include <nRF24L01.h>
#include <RF24.h>

/* ******************************************
    Factory default values
   ****************************************** */

enum GameOrientation
{
    goRegular,
    goPaddleRight,
    goUpsideDown,
    goPaddleLeft
};

enum GameMode
{
    //games
    gmBreakOut,
    gmTennis,
    
    //standard configuration menu
    gmSpeed,
    gmBrightness,
    
    //advanced configuration menu
    gmPaddleLeft,
    gmPaddleRight,
    
    //EEPROM: store current settings or reset to default
    gmEEPROM
};

enum GameSounds
{
    gsWall,        //sound: ball hits the wall
    gsPaddle,      //sound: ball hits the paddle
    gsPlayfield,   //sound: ball hits the BreakOut bricks (playfield)
    gsLost         //sound: ball gets lost
};

//defaults that are set, when "back to factory default" is selected in the extended menu
const GameMode        game_mode_default = gmBreakOut;    //first game to be started
const unsigned int    speed_default = 300;               //speed of the game in "milliseconds between moving the ball one pixel"
const byte            intensity_default = 0;             //brightness of the 8x8 matrix
const unsigned int    poti_leftmost_default = 200;       //restrict poti range to the left for a more natural feeling
const unsigned int    poti_rightmost_default = 823;      //... dito to the right
const GameOrientation orientation_default = goRegular;   //game orientation
const unsigned long   respawn_duration = 1500;           //milliseconds to wait after a ball got lost
const byte            Balls_max = 3;                     //maximum amount of balls in BreakOut
const byte            Tennis_win = 3;                    //amount of points needed to win tennis

//button press duration in milliseconds
const unsigned int    UniversalButtonPressedShort = 100;     //reset game / select menu item
const unsigned int    UniversalButtonPressedLong = 750;      //enter regular menu
const unsigned int    UniversalButtonPressedVeryLong = 3500; //enter advanced menu

//enter multiplayer mode
const unsigned long   MultiplayerQuestionMax = 2000;         //how long is the question mark shown, before the user can choose
boolean               MultiplayerQuestionButton = false;     //universal button pressed during rmMaster_init or rmSlave_init

//the speed defines how many milliseconds are between two ball movements
//the movement of the paddle is decoupled from the movement speed of the ball
//the maximum speed heavily depends on the processor type and speed
const unsigned int    speed_max = 50;                       //amount of screen refresh cycles in milliseconds that are wasted...
const unsigned int    speed_min = 500;                      //...until the ball moves on one pixel

//amount of LEDs installed in the device, should be 3
//changing this leads to multiple code parts that need adjustments
const byte            LED_count = 3;

//absolute y-coordinate where a paddle hit shall be counted (normally is 1 line away from the line where the paddle resides)
const byte            PaddleHit_Top    = 1;
const byte            PaddleHit_Bottom = 6;

//flags for the adjust speed mode
const unsigned long   Flag_Leave       = (unsigned long) 1 << 31;
const unsigned long   Flag_Leave_Ack   = (unsigned long) 1 << 30;
const unsigned long   Mask_Speed       = 1023;

//EEPROM fingerprint for detecting, if the EEPROM has ever been initialized by TeleBall
const byte EEPROM_Fingerprint_len = 8;
const byte EEPROM_Fingerprint[8]  = {'T', 'e', 'l', 'e', 'B', 'a', 'l', 'l'};

/* EEPROM layout
   Bytes    Type            Value
   00..07   chars           TeleBall device fingerprint
   08..09   unsigned int    ball speed (variable: Speed)
   10       byte            display intensity (variable: Intensity)
   11..12   unsigned int    leftmost poti position (variable: PotiLeftmost)
   13..14   unsigned int    rightmost poti position (variable: PotiRightmost)
*/
const byte locFingerprint   =  0;
const byte locSpeed         =  8;
const byte locIntensity     = 10;
const byte locPotiLeftmost  = 11;
const byte locPotiRightmost = 13;

//needs to be declared here to access the enums (strange compiler behaviour)
void calculateBallMovement(GameMode nowplaying);
void playSound(GameSounds whichsound);

/* ******************************************
    Global Game Variables
   ****************************************** */

GameOrientation Orientation = orientation_default;

//current speed of the game
//unsigned long (i.e. 4 bytes) due to RadioPayloadSize == 4
unsigned long Speed = speed_default;
unsigned long Speed_Old = Speed;

unsigned int Paddle = 0;                                //current x-position of paddle
unsigned int Paddle_Old = Paddle;
unsigned int Paddle_Remote = 0;
unsigned int Paddle_Remote_Old = Paddle_Remote;

byte Intensity = intensity_default;            //brightness of the display
byte Intensity_Old = Intensity;                

//poti range restriction for a more natural game feeling
unsigned int PotiLeftmost = poti_leftmost_default;
unsigned int PotiRightmost = poti_rightmost_default;
unsigned int PotiLeftmost_Old = PotiLeftmost;
unsigned int PotiRightmost_Old = PotiRightmost;

//current ball position
char BallX;                //a signed variable is used intensionally to...                     
char BallY;                //...cater for off-screen situations
char BallX_Old = BallX;
char BallY_Old = BallY;

//current ball speed in x and y direction
//note: the "char" variable can be negative, so -1 in BallDX means,
//that it moves to the left
char BallDX = 0;
char BallDY = 0;
char BallDX_tbs = 0;
char BallDY_tbs = 0;

//remember old values during configuration
byte rBallX, rBallY, rBallX_Old, rBallY_Old;
char rBallDX, rBallDY, rBallDX_tbs, rBallDY_tbs;

//flag, if a full reset of the game is to be performed
boolean perform_reset = true;

//flag, to distinguish between gameplay and the various configuration modes    
GameMode game_mode = game_mode_default;
GameMode game_mode_old = game_mode;

//flag to determin, if the game is currently in a loop state due to won or lost
boolean WonOrLostState = false;

//BreakOut only: amount of balls left and current level
byte Balls;
byte Balls_Old = 0;
byte Level;

//Tennis only: points
char TennisPoints = 0;
char TennisPoints_Old = -1;
char TennisPoints_Remote = 0;

//the timer is used to de-couple the paddle movement from the ball-speed
//i.e. it is the central instance for the overall game speed
unsigned long Timer = 0;

//the respawn_timer is used to wait until the next ball appears after you lose one
unsigned long respawn_timer = 0;

//used for measuring a quick paddle movement right before the ball hits the paddle
//to give the ball an extra spin; this is needed in situations, where you otherwise
//would not be able to clear all "bricks".
unsigned int LastPaddlePos = 0;
unsigned int LastPaddlePos_Remote = 0;
const byte PaddleSpeedThreshold = 1;

//universal button incl. debouncing
unsigned long UniversalButtonPressedStartTime = 0;
boolean UniversalButton_firstcontact = true;

unsigned long MultiplayerQuestionTime = 0;
unsigned long MultiplayerWaitStart = 0;

//breakout: screen memory for storing the current level
byte bricks[8][8];

/* ******************************************
    MAX7221 connections to 8x8 LED matrix

    DP => ROW1        DG1 => COL1
    A  => ROW2        DG2 => COL2
    B  => ROW3        DG3 => COL3
      ...                ...    
    G  => ROW8        DG8 => COL8
    
    Additionally:
    
    1. Connect DIN, CLK, CS as shown below to digital inputs of the Arduino Nano
    2. Connect VCC to 5V and GND to GND of the Arduino Nano
   ****************************************** */
   
const byte DataIn = 2;    //D2 => DIN
const byte CLK    = 3;    //D3 => CLK
const byte LOAD   = 4;    //D4 => CS

//create a new object to control the 8x8 LED matrix
LedControl Matrix = LedControl(DataIn, CLK, LOAD, 1);


/* *************************************************
    10k potentiometer to A7: paddle
    unused analog pin for random seed
    PWM enabled digital pin for audio
    3 digital pins for remaining ball LEDs
    Universal Control Button
   ************************************************* */
   
const byte potPaddle     = A7;
const byte UnusedAnalog  = A6;

const byte PWM_Audio     = 9;      //D9: Speaker+ ("LS+")

const byte BallDisplay[LED_count] = {5, 6, 7}; //LED #1 at D5, LED #2 at D6, LED #3 at D7

const byte UniversalButton   = 8;  //D8: "Button+"


/* ******************************************
    Levels / Graphics / Patterns / Melodies
   ****************************************** */

//this is the level pattern of the "bricks"
//modify to create tougher or easier levels
const byte Levels = 3;
const byte bricks_levelheight[Levels] = {3, 4, 4};
const byte bricks_reset[Levels][4][8] PROGMEM =
{
    {
        {1, 1, 1, 1, 1, 1, 1, 1},
        {1, 1, 1, 1, 1, 1, 1, 1},
        {1, 1, 1, 1, 1, 1, 1, 1},
        {0, 0, 0, 0, 0, 0, 0, 0}
    },
    
    {
        {1, 0, 1, 1, 1, 1, 0, 1},
        {1, 1, 0, 1, 1, 0, 1, 1},
        {0, 1, 1, 0, 0, 1, 1, 0},
        {0, 0, 1, 1, 1, 1, 0, 0}
    },
    
    {
        {1, 1, 1, 1, 1, 1, 1, 1},
        {1, 1, 1, 1, 1, 1, 1, 1},
        {1, 1, 1, 1, 1, 1, 1, 1},
        {1, 1, 1, 1, 1, 1, 1, 1}
    }
};

// :-) smiley shown, if you win the game
const byte smiley_won[8] PROGMEM = 
{
    0b00111100,
    0b01000010,
    0b10100101,
    0b10000001,
    0b10100101,
    0b10011001,
    0b01000010,
    0b00111100    
};

// :-| smiley shown, if you loose the game
const byte smiley_lost[8] PROGMEM = 
{
    0b00111100,
    0b01000010,
    0b10100101,
    0b10000001,
    0b10111101,
    0b10000001,
    0b01000010,
    0b00111100    
};

// checkerboard pattern for selecting brightness
const byte select_brightness[8] PROGMEM = 
{
    0b10101010,
    0b01010101,
    0b10101010,
    0b01010101,
    0b10101010,
    0b01010101,
    0b10101010,
    0b01010101
};

//left arrow: select leftmost paddle position
const byte arrow_left[8] PROGMEM = 
{
    0b00000000,
    0b00010000,
    0b00100000,
    0b01111110,
    0b00100000,
    0b00010000,
    0b00000000,
    0b00000000
};

//right arrow: select rightmost paddle position
const byte arrow_right[8] PROGMEM = 
{
    0b00000000,
    0b00001000,
    0b00000100,
    0b01111110,
    0b00000100,
    0b00001000,
    0b00000000,
    0b00000000
};

//EEPROM: store current configuration
const byte eeprom_store[8] PROGMEM =
{
    0b11111111,
    0b10000001,
    0b10111101,
    0b10100101,
    0b10100101,
    0b10111101,
    0b10000001,
    0b11111111
};

//EEPROM: revert to factory default
const byte eeprom_defaults[8] PROGMEM =
{
    0b10000001,
    0b01000010,
    0b00100100,
    0b00011000,
    0b00011000,
    0b00100100,
    0b01000010,
    0b10000001,
};

//question mark: enter multiplayer mode
const byte question_multiplayer[8] PROGMEM = 
{
    0b00011000,
    0b00000100,
    0b00011000,
    0b00100000,
    0b00011000,
    0b00000000,
    0b00001000,
    0b00000000
};

const byte yes_multiplayer[8] PROGMEM =
{
    0b00011000,
    0b00011000,
    0b00011000,
    0b00011000,
    0b00011000,
    0b00000000,
    0b00011000,
    0b00011000
};

//maximum length of any melody
//zero padding of all melodyies needs to be adjusted when changing this
//and hard coded [12] in playMelody function header
const byte melody_maxlen = 12;

//the larger, the quicker the melodies are played
const float melody_speed = 2.5f;

const byte melody_advance_level_len = 7;
const unsigned int melody_advance_level[2][melody_maxlen] PROGMEM =
{
    { 392, 392, 392, 440,  392, 494,  523, 0, 0, 0, 0, 0},    //frequency
    { 500, 250, 250, 500, 1000, 500, 2000, 0, 0, 0, 0, 0}     //duration, 1000 = 1 full beat
};

/* *************************************************
    NRF24L01+ radio
   ************************************************* */

//reflect the wiring on the PCB
const byte RadioCE             = A0;
const byte RadioCS             = A1;

//hardcoded address for sending and listening
//if we'd ever think about un-jam-ing, some other logic needs to be developed including
//a "root" address and then different addresses plus different channel
byte RadioAddress[6]           = {"TELEB"}; 

//need to be 4 bytes long (or, if RadioPayloadSize is other than 4 an appropriate memory buffer)
unsigned long RadioMasterToken  = 2309;        //initial negotiation: signal that this device is master
unsigned long RadioSlaveToken   = 4711;        //initial negotiation: signal that this device is slave
unsigned long RadioMasterWaitQ  = 2310;        //master waiting to start while slave still decides
unsigned long RadioSlaveWaitA   = 4712;        //slave acknowledging that it is ready to play
unsigned long RadioMasterSCP    = 7;           //master's poll code when slave is in speed change mode
                                               //small number not interfere with the bitfields during mode changes
unsigned long RadioMasterSCA    = 2312;        //master's ACK when slave ends speed change mode

//size of all send and receive packets, should be: 4; maximum possible: 32
//changing this from 4 to another size leads to multiple code pieces that need adjustments
const byte RadioPayloadSize    = 4;           

const byte RadioPipe           = 1;            //we only need one pipe, hard code it to 1

//milliseconds, until next Radio command, needs to be timed together with RadioWait_Max
const int RadioCycle           = 200;
unsigned long Last_RadioCycle  = 0;

//wait and listen randomly between RadioWaitMin and
//RadioWaitMax, before 
const int RadioWait_Min        = 500;
const int RadioWait_Max        = 850;  //this needs to be carefully timed due to RadioTimeOutVal
unsigned long RadioWait        = 0;

//mechanism for handling cases, where the transmission is not working any more,
//e.g. the other player switches-off his device, walks out of range, etc.
unsigned long RadioTimedOut          = 0;
const unsigned long RadioTimeOutVal  = 3000;  //after 3 seconds of "nothing", the radio is considered as timed-out

//save battery: time in milliseconds after which the device powers down
//the radio and ignores further tennis request
const unsigned long RadioPowerSaveTime = 120000;

//avoid jamming the ACK FIFO (TX FIFO) by keeping track of uploaded ACK payloads
boolean RadioACKuploaded      = false;

//create a new radio object
RF24 Radio(RadioCE, RadioCS);

//master/slave state machine
enum
{
    //some checks are done via "> rmNone", i.e. it is important that the modes are in order
    rmIgnore                    = -2,   //do not scan any more, but ignore other TeleBall devices
    rmNone                      = -1,   //no other TeleBall device found
    
    //initial find devices and ask the question
    rmMaster_init               = 0,    //about to enter Master mode
    rmSlave_init                = 1,    //about to enter Slave mode
    rmMaster_wait               = 2,    //waiting for Slave to start the game
    rmSlave_wait                = 3,    //waiting for Master to start the game
    
    //standard run mode
    rmMaster_run                = 4,    //running in Master mode    
    rmSlave_run                 = 5,    //running in Slave mode
    
    //special modes for reset and speed adjustments
    rmMaster_reset              = 6,    //Master device resetting
    rmSlave_reset               = 7,    //Slave device resetting
    rmMaster_speedset_by_Master = 8,    //Master device in speed set mode
    rmMaster_speedset_by_Slave  = 9,    //Master device listening to Slave's speed set
    rmSlave_speedset_by_Master  = 10,   //Slave device listening to Master's speed set
    rmSlave_speedset_by_Slave   = 11    //Slave device in speed set mode
} RadioMode = rmNone;

//RadioGameDataFromMaster is the payload sent from master to slave
//IMPORTANT: BITFIELD NEEDS TO BE RadioPayloadSize IN SIZE, so padding is used
struct  //use bit fields to squeeze everything in two bytes
{
    unsigned int Paddle           : 3;
    unsigned int BallX            : 3; 
    unsigned int BallY            : 3;
    unsigned int TennisPoints     : 2;
    unsigned int WonOrLostState   : 1;
    unsigned int Reset            : 1;  //master initiates reset
    unsigned int Reset_Ack        : 1;  //master acknowledges a reset request send by slave
    unsigned int SpeedSet         : 1;  //master initiated a change in the game's speed
    unsigned int SpeedSet_Ack     : 1;  //master acknowledges a speedset request by slave
    unsigned int Sound_Wall       : 1;  //make slave play: ball hits a wall
    unsigned int Sound_Paddle     : 1;  //make slave play: ball hits a paddle
    unsigned int Sound_Lost       : 1;  //make slave play: lost ball
    
    //the padding cannot be arbitrarly done as "padding : <amount>" due to compiler specifics
    unsigned int unused_padding1  : 1;
    unsigned int unused_padding2  : 1;
    unsigned int unused_padding3  : 1;
    unsigned int unused_padding4  : 1;
    unsigned int unused_padding5  : 1;
    unsigned int unused_paddingx  : 8;  
} RadioGameDataFromMaster;

//RadioGameDataFromSlave is the payload sent from slave to master during ACK
//IMPORTANT: BITFIELD NEEDS TO BE RadioPayloadSize IN SIZE, so padding is used
struct  //also uses bit fields
{
    unsigned int Paddle           : 3;
    unsigned int Reset            : 1;   //slave initiates reset
    unsigned int Reset_Ack        : 1;   //slaves acknowledges a reset initiated by the master
    unsigned int SpeedSet         : 1;   //slave initiates a change in the game's speed
    unsigned int SpeedSet_Ack     : 1;   //slave acknowledges a speedset initiated by the master
    
    //the padding cannot be arbitrarly done as "padding : <amount>" due to compiler specifics    
    unsigned int unused_padding1  : 1;
    unsigned int unused_paddingx  : 24;    
} RadioGameDataFromSlave;
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
void loop()
{   
    if (perform_reset)
        reset();
        
    //check for other player/device and set the variable RadioMode,
    //i.e. no radio connection, act as master or act as slave
    radioScanAndDetermineMode();
    
    //handle various input ports and the orientation
    handleInput();
    handleOrientation();
    handleBrightness();
    
    switch (game_mode)
    {
        case gmBreakOut:    playBreakOut();        break;
        case gmTennis:      playTennis();          break;
        
        case gmSpeed:       adjustSpeed();         break;
        case gmBrightness:  adjustBrightness();    break;   
        
        case gmPaddleLeft:     
        case gmPaddleRight:
            adjustPaddle();
            break;

        case gmEEPROM:      manageEEPROM();        break;            
    }
    
    //if radio is active (aka if tennis), time out, e.g. because the other
    //device was switched off or it was moved out of transmission range, etc.
    if (RadioMode > rmNone && millis() > RadioTimedOut)
    {
        Radio.flush_tx();
        radioEmptyReadFIFO();
        game_mode = gmTennis;           //make sure, that tennis is reset, when calling reset() ...
        reset();                        //... game_mode could be config modes like gmSpeed, etc.
        tennisSwitchToBreakOut(false);  //switch to BreakOut but continue to try to find another device for tennis
    }    
}

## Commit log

2014-12-26 GIT repo created and V1.1 files added
    [BreakOut-8x8-rev2.brd, BreakOut-8x8-rev2.sch, case_body_v2.stl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]
2014-12-26 bugfixes: tennis, pairing, eeprom selector
    [TeleBall.ino]
2014-12-30 bugfixes, SRAM optimization, menu changes
    [TeleBall.ino]
2014-12-30 final bugfixes for V1.2 release
    [TeleBall.ino]
2015-01-04 wip documentation and pages
    [case_lid_v2.stl]
2016-06-03 BOM update

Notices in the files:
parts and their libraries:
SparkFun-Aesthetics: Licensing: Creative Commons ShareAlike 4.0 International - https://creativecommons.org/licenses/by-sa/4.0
